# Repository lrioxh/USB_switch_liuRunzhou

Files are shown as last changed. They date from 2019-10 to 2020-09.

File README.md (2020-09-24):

=============基于51单片机的嵌入式USB开关===============

功能：蓝牙遥控，定时，检测电流，红外感应

使用介绍见 instructions.docx

产品效果见 产品介绍.pptx

更新日志：

----------20190901-----ver0.1----初稿完成--------------------------

----------20190925-----ver1.0----原理图·pcb完成-------------------

----------20190930-----ver2.0----添加了红外模块，pcb焊接完成----

----------20191010-----ver2.1----程序调试完毕，添加了描述文件----

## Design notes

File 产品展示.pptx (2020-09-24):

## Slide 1

嵌入式USB开关

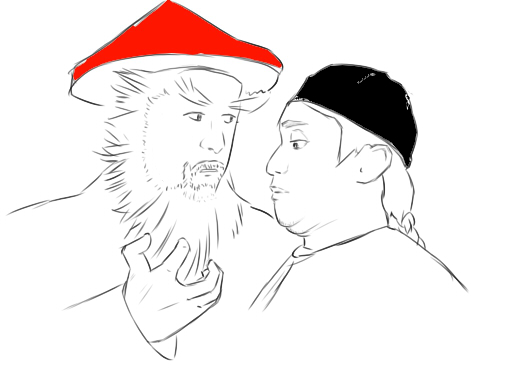
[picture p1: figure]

全都要®工作室

Designed by 刘润洲

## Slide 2

- Content

是什么
器件及功能

01

做什么
应用

02

为什么
产品故事

03

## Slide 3

01

是什么
器件及功能

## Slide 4

器件及功能

概念设计

数码管

蓝牙模块

MCU

继电器

USB

AD采样

电流传感器

红外模块

按键

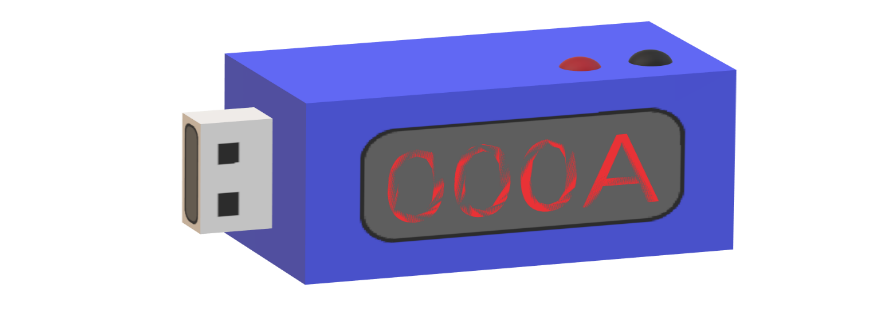
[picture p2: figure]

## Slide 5

器件及功能

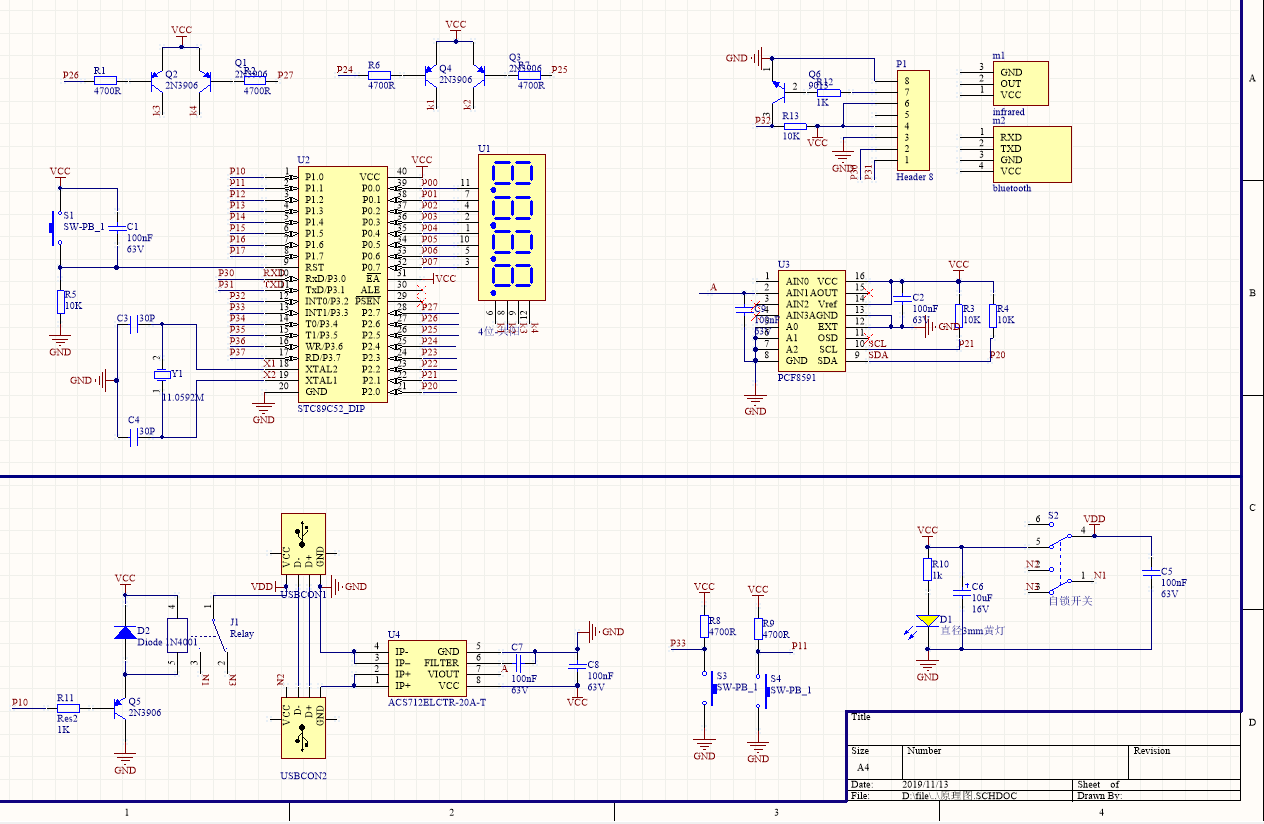
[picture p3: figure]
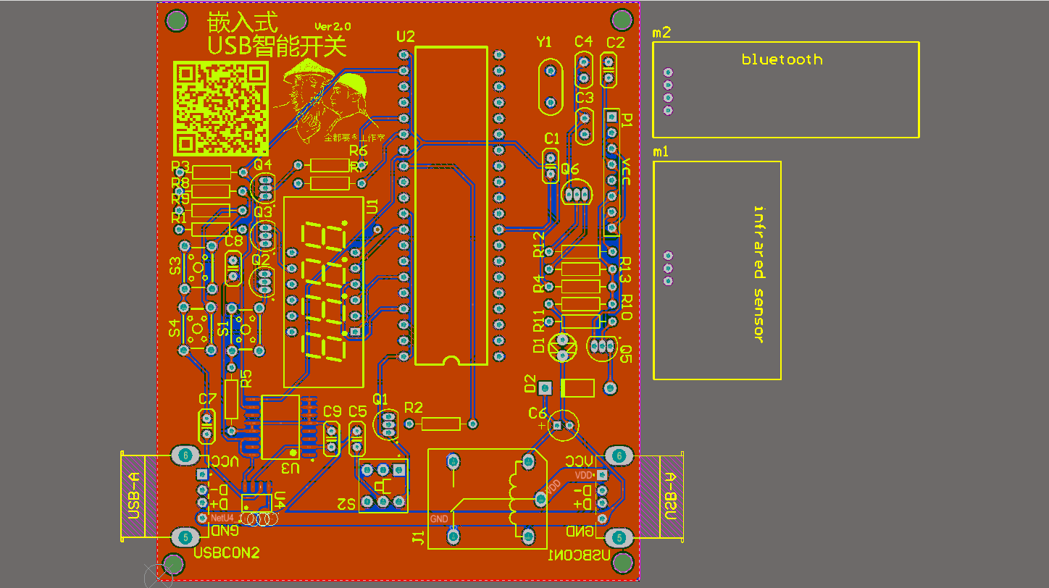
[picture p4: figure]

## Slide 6

Comment | Description | Footprint | LibRef | Quantity | Price
Cap | Capacitor CBB聚乙烯薄膜电容 | Capacitor-Disk-Middle | Cap Nicklon | 6 | 0.03
30P | 无极性电容 | CAP-0.1 | CAP | 2 | 0.03
直径3mm黄灯 | 直径3mm的发光二极管 | LED_#3 | LED_3#黄灯 | 1 | 0.03
Diode 1N4001 | 1 Amp General Purpose Rectifier | DO-41 | Diode 1N4001 | 1 | 0.014
Relay | 继电器-单刀双掷 | RELAY-5 | Relay | 1 | 0.6
2N3906 | PNP General Purpose Amplifier | TO-92A | 2N3906 | 5 | 0.046
Res | Resistor | AXIAL-0.8 | Res2 | 11 | 0.01
SW-PB | Switch | KEY-pad | SW-PB | 2 | 0.065
自锁开关 | 自锁开关 | sw_8.5mm | SW DPDT | 1 | 0.5
4位-共阳 | 4位一体共阳数码管 0.36英寸30mm*14mm*7.2mm | SEG4_3641 | 4位-共阳 | 1 | 0.95
STC89C52 | STC89C52_40I | LQFP-44 | STC89C52RC | 1 | 2.5
PCF8591 | PCF8591 AD采集芯片 | DIP-16 | PCF8591 | 1 | 2.8
ACS712ELCTR-5A-T | 传感器 | SOIC-8_150mil | ACS712ELCTR-5A-T | 1 | 2.5
USB-4P | USB CONNECTOR | USB-A | USB-4P | 2 | 0.1
11.0592M | 晶振 | cry卧式 | XTAL DIP | 1 | 0.2
蓝牙模块 | Bluetooth3.0串口集成模块 | -- | -- | 1 | 6
红外模块 | 人体红外感应 | -- | -- | 1 | 5
Component Total Price | | Process Cost | Packing Cost | | Total Cost
22.004 | | 2 | 2 | | 26

注：1）价格信息综合来源于立创商城，淘宝，阿里巴巴；

器件及功能

BOM表

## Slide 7

器件及功能

不用时作为导线

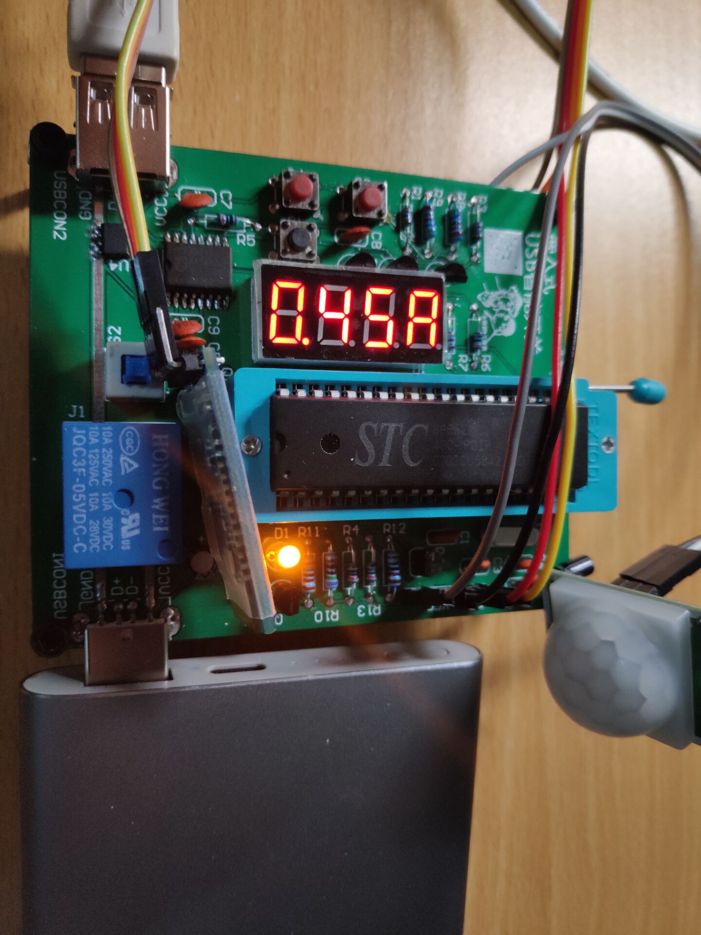
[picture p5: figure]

0

蓝牙远程控制

测量实时电流

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
自动断电

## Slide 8

器件及功能

按键，定时，蓝牙的

视频演示

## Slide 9

器件及功能

按键，定时，蓝牙的

视频演示

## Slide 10

If（长按按键红外使能）{
If（外电路手动断开）{ //蓝牙或按键断开 休息时
If（人离开一段时间）{
If（检测到人）{
外电路联通；
If（人离开）{ //只有红外打开，才能用红外关闭
外电路断开；
}
}
}
}
If（手动打断）{ //蓝牙或按键
参数清零到 红外使能 后；
}
}

器件及功能

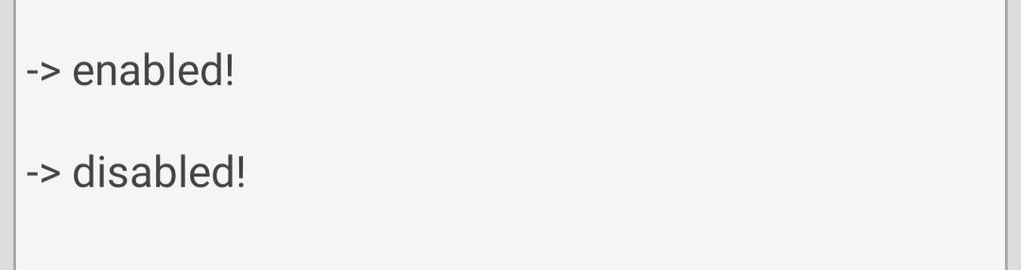
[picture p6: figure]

人体红外的

现场演示

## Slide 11

02

做什么
应用

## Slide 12

应用

两大特点

7/50

照明

IoT

嵌入式
(可拓展性
可移植性)

过渡性

风扇

数据线

移动电源

手机，平板

电源适配器

……

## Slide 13

03

为什么
产品故事

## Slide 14

产品故事

- 有很多想法……
- 从idea到实际产品……
- 延时，延时，延时…….

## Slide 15

产品故事

09/01

初稿完成

09/30

添加了红外模块，pcb焊接完成

开发
日志

+

09/25

原理图·pcb完成

10/10

程序调试完毕，上传GitHub

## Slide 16

感谢观看 THANKS

全都要®工作室

您的需求，
全都要®解决。

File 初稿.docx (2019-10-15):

嵌入式USB开关

18级刘润洲

设计方案：

1. 产品结构

如下图所示，MCU通过串口与蓝牙模块连接，蓝牙可与手机、电脑等智能设备配对。MCU接受串口或按键指令，由继电器控制USB通断，也可接受蓝牙串口时间信息，实现定时开关。外电路接通后，由电流传感器和AD转换组成的电流计模块可以测得外电路即时电流（精度约为105mA），通过IIC总线发送给MCU。MCU经过计算将电流值输出显示于数码管。而当外电路电流测量值小于精度时可认为电流为0（外电路无负载），MCU延时5min后继电器上电切断外电路USB；当电流大于4.5A时认为外电路过载，直接切断电路。内电路电源由外电路USB提供（5V），电源开关同时兼任了继电器常闭/敞开模式转换。

按键

蓝牙模块

MCU

继电器

USB

电流传感器

AD采样

数码管

2. 功能参数

USB供电，可实现：

- 蓝牙及按键控制外电路USB通断
- 外电路定时通断
- 测量并显示外电路电流
- 外电路电流小于一定值延时切断电路，高于一定值时立刻切断电路
- 内电路未接通时外电路常通，只作为导线没有额外负载

MCU：STC89C52；

蓝牙模块：HC-05，功率等级class 2，有效距离＞10m；

继电器：JQC3F-05VDC，5脚；

AD芯片：PCF8951（贴片），8位AD/DA转换，精度1/256；

电流传感器：ACS712TELC-05B，量程±5A，精度185mV/A；

数码管：3641 4位共阳；

3. 外观设计


4. 应用场景
- USB充电设备充满后自动断电；
- 遥控及定时USB开关，理论上可作为一切USB供电设备的遥控及定时开关，如可实现在床上遥控台灯，定时关闭小电扇等；
- 测量电流；
- 电路过载保护；
- 小微化后可嵌入变压器、数据线、充电宝中。

市场营销论证：

1. 市场分析（STP）
a. 市场细分

以USB供电设备使用频率和对本产品感兴趣程度（注：由个人受产品惠益和新事物接受能力两方面刻画）两个维度对消费者群分四类：

USB供电设备使用频率

对本产品感兴趣程度

A类

特征人群：大学生等

B类

特征人群：上班族，高收入阶层等

C类

特征人群：中小学生等

D类

特征人群：农民，工人等

b. 目标市场

选择集中性市场策略，以A类市场为目标市场。1）初期生产和营销规模小，单一市场集中优势力量，更有利于适销对路，降低成本，提高知名度。2）目前市场上没有与本产品相同的商品（注：见1.c市场定位）。本产品属于新型商品，消费者并不了解其功能和用途，故选择接受新事物能力较强的人群。3）产品功能更符合A类市场需求，A类人群能从产品中获得更大惠益。大学生会频繁使用手机、平板、充电宝等USB充电的设备和台灯、风扇等USB供电设备；可改善宿舍体验，如熄灯后照明的台灯可在床上遥控关闭和打开，USB小风扇不想吹一整夜可以定时关闭等。

生产销售稳定后可考虑拓宽B类C类市场，或发展高端市场如智能数据线，智能充电宝等，或加盟阿里、小米、华为等的物联网/智能设备体系。

c. 市场定位

市场上与本产品相似的商品主要有A米家智能插座（WiFi连接，3转5单插，三款￥45-85不等）和B公牛天猫精灵智能魔方USB插座（蓝牙连接，3转5三插+三USB口，￥80）两款。本产品与以上两款定位均不同：1）控制USB低压电路，小型用电器，更符合目标市场（大学生很少使用大型用电器）。2）单USB独立控制（如B的开关同时控制插上的全部用电器，不能单独开关）。3）使用便利，只需在现有设备基础上加装类似转接头的装置，相比于略显笨重的插座十分轻小便捷。4）不使用时等同导线没有额外负载，对原电路无影响。5）价格低，预计单价￥25左右（注：见2.b Price）。

2. 生产与营销（4P）
a. Product

产品集遥控/定时/自动断电/电流测量多种用途于一身，功能多样；成品预计U盘大小，蓝牙配对后即插即用，轻小便捷；可与多种用电器自由组合；外观包装倾向于简约感和现代感；产品售出无售后。

b. Price

估计成本（价格单位RMB元/件）：

Comment | Description | Footprint | LibRef | Quantity | Price
Cap | Capacitor CBB聚乙烯薄膜电容 | Capacitor-Disk-Middle | Cap Nicklon | 6 | 0.03
30P | 无极性电容 | CAP-0.1 | CAP | 2 | 0.03
直径3mm黄灯 | 直径3mm的发光二极管 | LED_#3 | LED_3#黄灯 | 1 | 0.03
Diode 1N4001 | 1 Amp General Purpose Rectifier | DO-41 | Diode 1N4001 | 1 | 0.014
Relay | 继电器-单刀双掷 | RELAY-5 | Relay | 1 | 0.6
2N3906 | PNP General Purpose Amplifier | TO-92A | 2N3906 | 5 | 0.046
Res | Resistor | AXIAL-0.8 | Res2 | 11 | 0.01
SW-PB | Switch | KEY-pad | SW-PB | 2 | 0.065
自锁开关 | 自锁开关 | sw_8.5mm | SW DPDT | 1 | 0.5
4位-共阳 | 4位一体共阳数码管 0.36英寸30mm*14mm*7.2mm | SEG4_3641 | 4位-共阳 | 1 | 0.95
STC89C52 | STC89C52_40I | LQFP-44 | STC89C52RC | 1 | 2.5
PCF8591 | PCF8591 AD采集芯片 | DIP-16 | PCF8591 | 1 | 2.8
ACS712ELCTR-5A-T | 传感器 | SOIC-8_150mil | ACS712ELCTR-5A-T | 1 | 2.5
USB-4P | USB CONNECTOR | USB-A | USB-4P | 2 | 0.1
11.0592M | 晶振 | cry卧式 | XTAL DIP | 1 | 0.2
蓝牙模块 | Bluetooth3.0串口集成模块 | -- | -- | 1 | 6
Component Total Price | | Process Cost | Packing Cost | | Total Cost
17.004 | | 2 | 2 | | 21

注：1）价格信息综合来源于立创商城，淘宝，阿里巴巴；

2）若能与原料供应、PCB生产、产品外观及包装相关厂商建立长效合作则可能进一步降低成本。

根据成本预估，零售初步定价￥24.9，批发价格￥22-23。

c. Place

分销渠道包括不限于：1）附近省市大学内超市零售；2）淘宝等网店，微商及官网的零售和批发；3）在线上线下销售平台与台灯、风扇、数据线、充电宝等设备捆绑销售；4）抓住每年暑期开学季黄金时期，加入各店销售的“大一新生入学大礼包”等开学季组合产品。

d. Promotion

立足微信，QQ空间，微博，bilibili，知乎，贴吧等青年聚集的网络平台展开宣传，具体方法例如：1）在上述社交平台撰文或邀请有一定影响力的自媒体发文提及或推荐本产品（例，“宿舍必备神器盘点”）；2）邀请知名up主（包括vup）做产品测评或推广；3）在暑期相关微博话题#开学必备单品#，b站专栏活动#开学大作战#，知乎热榜（开学必备清单），贴吧帖子中软推广；4）在微博，b站转发抽奖，奖品为本产品+不等数额奖学金。

尝试与知名IP合作，如崩坏，初音未来等。发售限定外观及包装的产品，附赠特典。

尝试在小说，动画，电影，电视剧等作品中使用本产品。

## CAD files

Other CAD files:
程序/main.OBJ
程序/STARTUP.OBJ
程序/delay.OBJ
程序/i2c.OBJ

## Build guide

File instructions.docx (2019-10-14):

# 嵌入式USB开关使用指南

18数科 刘润洲

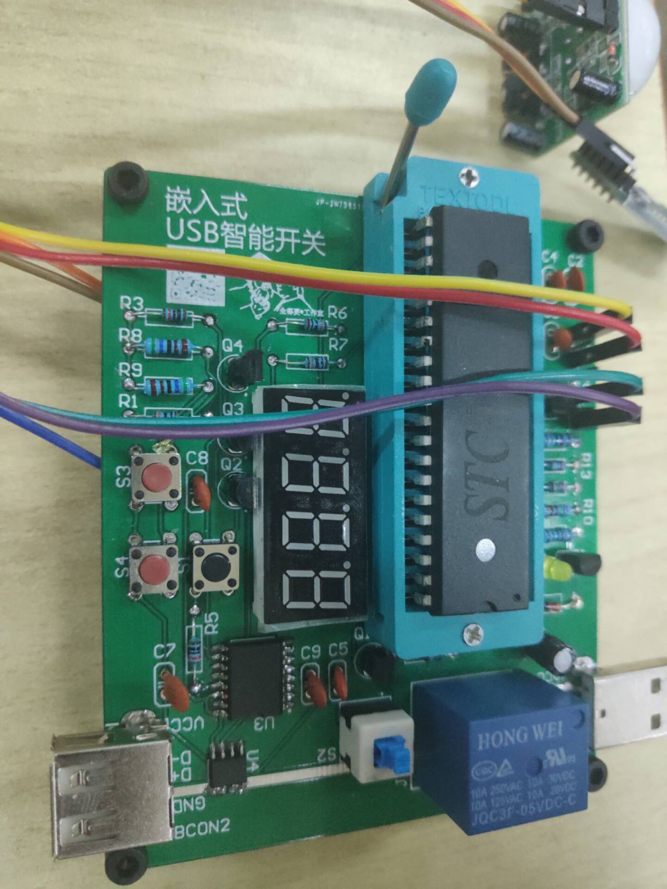
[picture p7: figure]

红外模块

蓝牙模块

自锁开关

按起USB公母口间为通路，可作为导线;

按下单片机上电，USB通过继电器控制通断

S1 复位按键

短按 开关数码管（默认关） S4 →

长按2s 使能红外感应（默认关）

红外开启后蓝牙串口回复“enabled!”

关闭后回复“disabled!”（详见图3）

短按 开关继电器（默认关） S3 →

TXD 反面：

GND RXD

VCC VCC

GND OUT

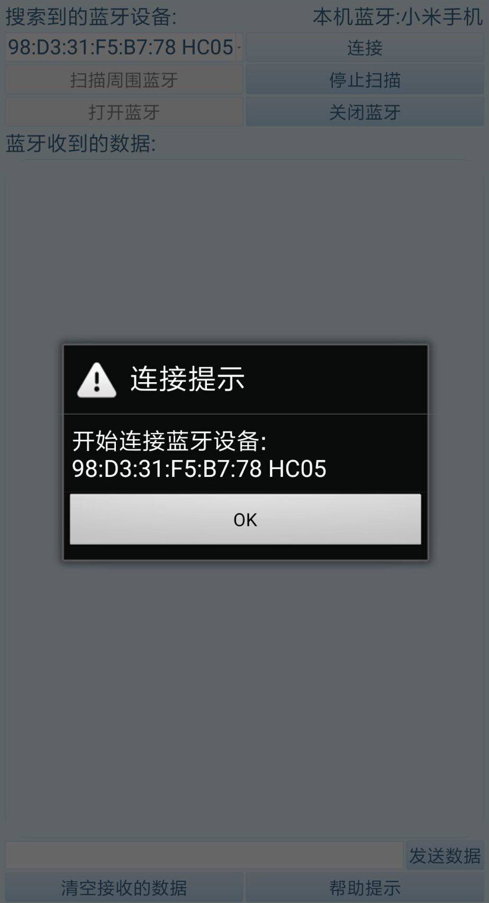
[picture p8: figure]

上电后蓝牙模块红灯闪烁，可用蓝牙助手与其配对链接，配对成功后红灯由快闪变为双闪。

蓝牙助手app：. /base.apk（在本文件夹下）

设备名称如图，配对密码：1234

找不到设备可尝试从手机蓝牙设置里直接与“HC05”配对。

#尚不支持iOS设备。

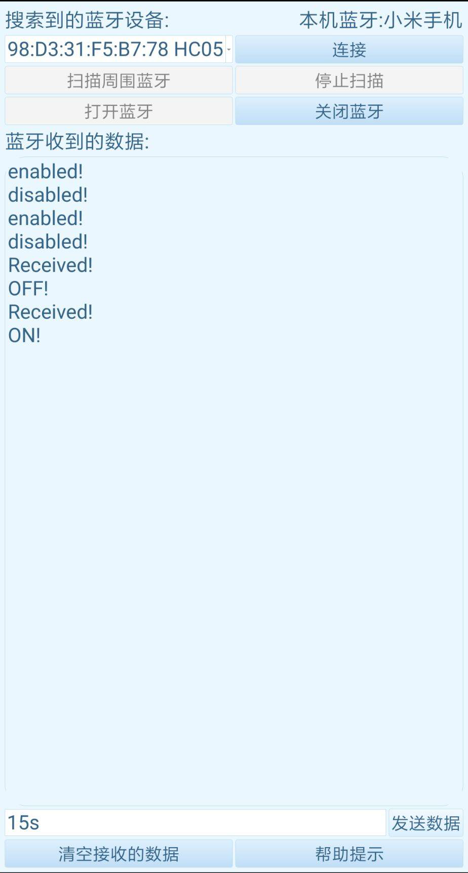
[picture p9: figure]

通过发送字符串“Ns “控制继电器通断，Ns为延时时间（秒），N为最高5位整数。

eg 输入0s则立即对继电器状态取反，并收到回复操作后当前继电器状态。

延时15s后继电器状态取反

红外使能和禁止标志

成功接受数据

操作完毕后继电器状态

长按S4使能红外后，在人离开的情况下 再次检测到人 且继电器关，则打开继电器；继电器由红外打开后 若检测到人离开 则延时关闭。上述条件任一不满足则不会触发。上述过程可人为打断，红外使能后自动初始化。

红外检测广角约150°，距离3m以内。红外较灵敏，建议置于黑箱中模拟无人环境。

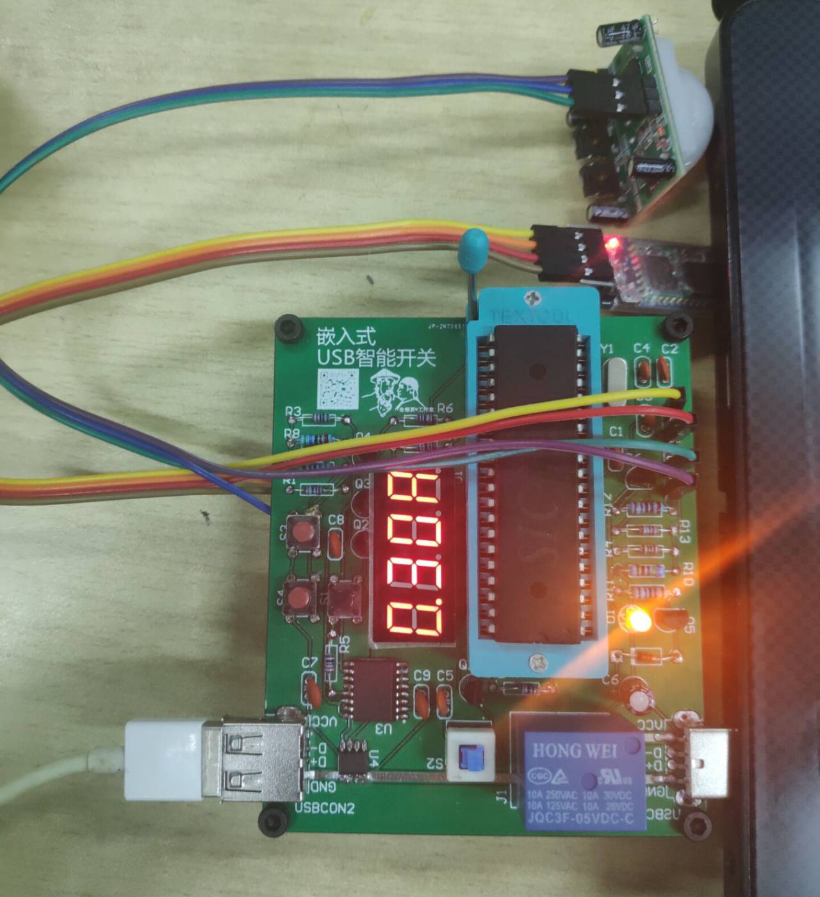
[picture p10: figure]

实时监测USB电流，电流过小（~0A）会延时关闭继电器及数码管；过大（~5A）则立即关闭。

短按S4打开数码管可查看当前电流。

正常工作如图所示。

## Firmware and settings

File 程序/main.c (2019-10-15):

#include<reg52.h>
#include<stdio.h>
#include "delay.h"
#include "i2c.h"

sbit k1=P2^4;
sbit k2=P2^5;
sbit k3=P2^6;
sbit k4=P2^7;
sbit red=P3^2;
sbit s3=P3^3;
sbit s4=P1^1;
sbit relay=P1^0;

unsigned char table[]={
0xc0, 0xf9 ,0xa4, 0xb0, 0x99, 0x92, 0x82, 0xf8, 0x80, 0x90,0x88};
unsigned char datas[6];        //uart datas
char *a=&datas;
char i,j= 0;
unsigned char receive,m=0;
unsigned char q=100;
unsigned char rdata,midcur;
unsigned int crt,p=0;
unsigned char dec,hun,thou=0;
bit key,flag,man,autoon,infrared=0;

unsigned long time_20ms,time,btn=0;		   //定时器计数
float Acurrent=0.0;				  //检测电流

void Init_Timer0(void);
void uartSendStr(unsigned char *s);
void UART_Init(void);
void uartSendByte(unsigned char dat);
void Scankey();
void LED();


void main (void)
{
	relay=1;  //off
	man=0;    //延时标志有人
	Init_Timer0();
	UART_Init();
	DelayMs(20);
	while(1)
	{
		q++;
		if(q>100){
			q=0;
			midcur=ReadADC(1);		//读取电流转化后的电压值
			//DelayMs(5);
		}

		Acurrent=(float)midcur*5.13/255;		//DA
												
		if(Acurrent>2.6)
		{
			//p=0;
			Acurrent=(Acurrent-2.6)/0.184;
		}
		else
		{
			//p++;
			Acurrent=0;
		}
		crt=Acurrent*100+0.5;
		
		if(crt<4){   //too low
			p++;}      //delay
		else if(crt>450){  //too high
		relay=1;}
		else{
			p=0;
		}
		
		if(p>30000){  //delay
		relay=1;      //OFF
			key=0;
			p=0;
		}
		
		if(flag==1){     //uart标志
			TR0=1;
			m=0;
			man=0;
			if(time_20ms/50>=time){  //记时延时
				TR0=0;
				flag=0;
				relay=~relay;
				time=0;
				time_20ms=0;
				if(relay==0){          //发送继电器情况
				uartSendStr("ON!\n");}
				else{uartSendStr("OFF!\n");}
			}
		}
		if(infrared==1){   //红外使能
		if(red==1&&man==0){  //检测无人且原本有人
			m++;
			if(m>200){       //检测无人且维持一定时间
			man=1;}}         //确定无人
		if(red==0&&man==0){
			m=0;}
		if(red==0&&man==1&&relay==1){  //检测有人且原本无人且继电器关
			m++;
			if(m>4){       //delay
			m=0;
			man=0;
			autoon=1;   //自动开
			relay=0;}}  //on
		if(red==1&&autoon==1){
		relay=1;   //off
		man=0;
		autoon=0;}}   //自动关
		
		LED();
		Scankey();
	}
}


void Init_Timer0(void)
{
	TMOD=0x01;	  //模式1，16位定时器
	TH0=0xb8;		  //20ms
	TL0=0x00;
	EA=1;
	ET0=1;
}

void Timer0_isr(void) interrupt 1 
{
	TH0=0xb8;
	TL0=0x00;
	
	time_20ms++;
}


void UART_Init(void)
{
    SCON=0x50;
    TMOD|=0x20;
    TH1=0xFD;         //9600 波特率
		TL1=TH1;  
    TR1=1;           //timer 1                        
    EA=1;
    ES=1;
}

void uartSendByte(unsigned char dat)
{
	unsigned char time_out;
	time_out=0x00;
	SBUF = dat;			  //将数据放入SBUF中
	while((!TI)&&(time_out<50))  //检测是否发送出去
	{time_out++;DelayUs2x(10);}	//未发送出去 进行短暂延时
	TI = 0;						//清除ti标志
}


void uartSendStr(unsigned char *s){
	while(*s!='\0')
	{
		uartSendByte(*s);  //单字节数据
		s++;
	 }
}

void UART_SER (void) interrupt 4
{
	if(RI)
	{
	  RI = 0;
		receive= SBUF;
		rdata=receive-'0';//接收转数字
		for(j=0;j<5;j++){ //循环压入数组
		*(a+j)=*(a+j+1);}
		*(a+5)=rdata;     //最后一位直接压入数组
		if(receive=='s'){ //传输完毕
			uartSendStr("Received!\n");
			time=datas[0]*10000+datas[1]*1000+datas[2]*100+datas[3]*10+datas[4];//转十进制数
			flag=1;
			for(j=0;j<6;j++){
		*(a+j)=0;}        //数组清零
			}
	}
	
	if(TI)
	{
	   TI = 0;
		}
}
void Scankey(){
	if(s4==0){
		DelayMs(5);
		if(s4==0){
			P0=0xff;
			key=~key;
			man=0;
			while(!s4){
				btn++;
				if(btn>20000){  //长按
				btn=0;
				infrared=~infrared;
				autoon=0;
				if(infrared==0){ //发回红外情况
				uartSendStr("disabled!\n");}
				else{uartSendStr("enabled!\n");}
				while(!s4);
				}
			}
		}
	}
	if(s3==0){
		DelayMs(5);
		if(s3==0){
			P0=0xff;
			relay=~relay;
			man=0;
			while(!s3);
		}
	}
}
	
void LED(){
	dec=crt%10;
	hun=crt%100/10;
	thou=crt/100;
	//for(i=0;i<4;i++){
		P0=0xff;
	if(key==1){
        switch(i)
		{
			case 0: k1 =0;k2 =1;k3 =1;k4 =1;i++;P0=table[10];break;
			case 1: k1 =1;k2 =0;k3 =1;k4 =1;i++;P0=table[dec];break;
			case 2: k1 =1;k2 =1;k3 =0;k4 =1;i++;P0=table[hun];break;
			case 3: k1 =1;k2 =1;k3 =1;k4 =0;i=0;P0=table[thou]&0x7f;break;
		};
		DelayUs2x(25);
	}
	//}
}

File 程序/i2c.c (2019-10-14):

#include "i2c.h"

#define  _Nop()  _nop_()  //定义空指令
                         
bit ack;	              //应答标志位

sbit SDA=P2^0;
sbit SCL=P2^1;

#define AddWr 0x90   //写数据地址 
#define AddRd 0x91   //读数据地址

void Start_I2c()
{
  SDA=1;   //发送起始条件的数据信号
  _Nop();
  SCL=1;
  _Nop();    //起始条件建立时间大于4.7us,延时
  _Nop();
  _Nop();
  _Nop();
  _Nop();    
  SDA=0;     //发送起始信号
  _Nop();    //起始条件锁定时间大于4μ
  _Nop();
  _Nop();
  _Nop();
  _Nop();       
  SCL=0;    //钳住I2C总线，准备发送或接收数据
  _Nop();
  _Nop();
}

void Stop_I2c()
{
  SDA=0;    //发送结束条件的数据信号
  _Nop();   //发送结束条件的时钟信号
  SCL=1;    //结束条件建立时间大于4μ
  _Nop();
  _Nop();
  _Nop();
  _Nop();
  _Nop();
  SDA=1;    //发送I2C总线结束信号
  _Nop();
  _Nop();
  _Nop();
  _Nop();
}

void  SendByte(unsigned char c)
{
 unsigned char BitCnt;
 
 for(BitCnt=0;BitCnt<8;BitCnt++)  //要传送的数据长度为8位
    {
     if((c<<BitCnt)&0x80)SDA=1;   //判断发送位
       else  SDA=0;                
     _Nop();
     SCL=1;               //置时钟线为高，通知被控器开始接收数据位
      _Nop(); 
      _Nop();             //保证时钟高电平周期大于4μ
      _Nop();
      _Nop();
      _Nop();         
     SCL=0; 
    }
    
    _Nop();
    _Nop();
    SDA=1;               //8位发送完后释放数据线，准备接收应答位
    _Nop();
    _Nop();   
    SCL=1;
    _Nop();
    _Nop();
    _Nop();
    if(SDA==1)ack=0;     
       else ack=1;        //判断是否接收到应答信号
    SCL=0;
    _Nop();
    _Nop();
}

unsigned char  RcvByte()
{
  unsigned char retc;
  unsigned char BitCnt;
  
  retc=0; 
  SDA=1;             //置数据线为输入方式
  for(BitCnt=0;BitCnt<8;BitCnt++)
      {
        _Nop();           
        SCL=0;       //置时钟线为低，准备接收数据位
        _Nop();
        _Nop();      //时钟低电平周期大于4.7us
        _Nop();
        _Nop();
        _Nop();
        SCL=1;       //置时钟线为高使数据线上数据有效
        _Nop();
        _Nop();
        retc=retc<<1;
        if(SDA==1)retc=retc+1; //读数据位,接收的数据位放入retc中
        _Nop();
        _Nop(); 
      }
  SCL=0;    
  _Nop();
  _Nop();
  return(retc);
}

void NoAck_I2c(void)
{
  
  SDA=1;
  _Nop();
  _Nop();
  _Nop();      
  SCL=1;
  _Nop();
  _Nop();              //时钟低电平周期大于4μ
  _Nop();
  _Nop();
  _Nop();  
  SCL=0;                //清时钟线，钳住I2C总线以便继续接收
  _Nop();
  _Nop();    
}

unsigned char ReadADC(unsigned char Chl)
 {
   unsigned char Val;
   Start_I2c();               //启动总线
   SendByte(AddWr);             //发送器件地址
     if(ack==0)return(0);
   SendByte(0x40|Chl);            //发送器件子地址
     if(ack==0)return(0);
   Start_I2c();
   SendByte(AddWr+1);
      if(ack==0)return(0);
   Val=RcvByte();
   NoAck_I2c();                 //发送非应位
   Stop_I2c();                  //结束总线
  return(Val);
 }

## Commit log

2019-10-14 initial commit of ver2.1
    [PcbLib1.PcbLib, STARTUP.OBJ, Schlib1.SchLib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]
2020-09-24 add 产品展示.ppt
